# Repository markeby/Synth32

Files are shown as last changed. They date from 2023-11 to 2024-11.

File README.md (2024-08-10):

# Synth32

This project was begun as a darivative of much simpler projects.

The goal is a psudo polyphonic analog and/or multi-timbral synthesizer that is digitally controlled.  

Utilizing components from the following manufacturers:

- Espressif 
  - ESP32 processors
- Sound Semiconductor, FatKeys™
  - VCO, VCF, VCA
- Adafruit
  - D/A Converter modules, I/O Expanders
- HiLetgo
  - 2.0 ADK Mini USB Host Shield
- Waveshare
  - Display module

The core of the system is an ESP-WROOM-32 ESP32 ESP-32S development board with a  USB development shield to interface a midi keyboard.
Any midi controller will work.  I am using an inexpensive Smason Graphite 49 on the serial MIDI and a Novation LaunchControl XL on the USB MIDI.
I intend to add bluetooth MIDI input as well.

The design is for 6 simultanous notes whether they be all of the same effect or split the keyboard to have dual effects but still be able to play cords.

This project has been on going for over a year now and will likely be a few more years of effort.

I have full schematics included as well as some of the experimental work I have done.  This is an unconventio02222nal modular design so as to maintain complete digital control. 

The tools used are:

- KiCad
- Visual SlickEdit IDE - I have used this for over 20 years and have tried others but found them either missing features or a colossal amount of plugins to figure out.
- Arduino-cli 
- Gnu make for Windows (could be used in Linux as well)
- Arduino IDE - I only am using the loader tool for OTA updates of the primary processor
- SimplySerial - The best serial terminal software I have seen for this application debugging.  
  Thanks Edward Wright (fasteddy516).

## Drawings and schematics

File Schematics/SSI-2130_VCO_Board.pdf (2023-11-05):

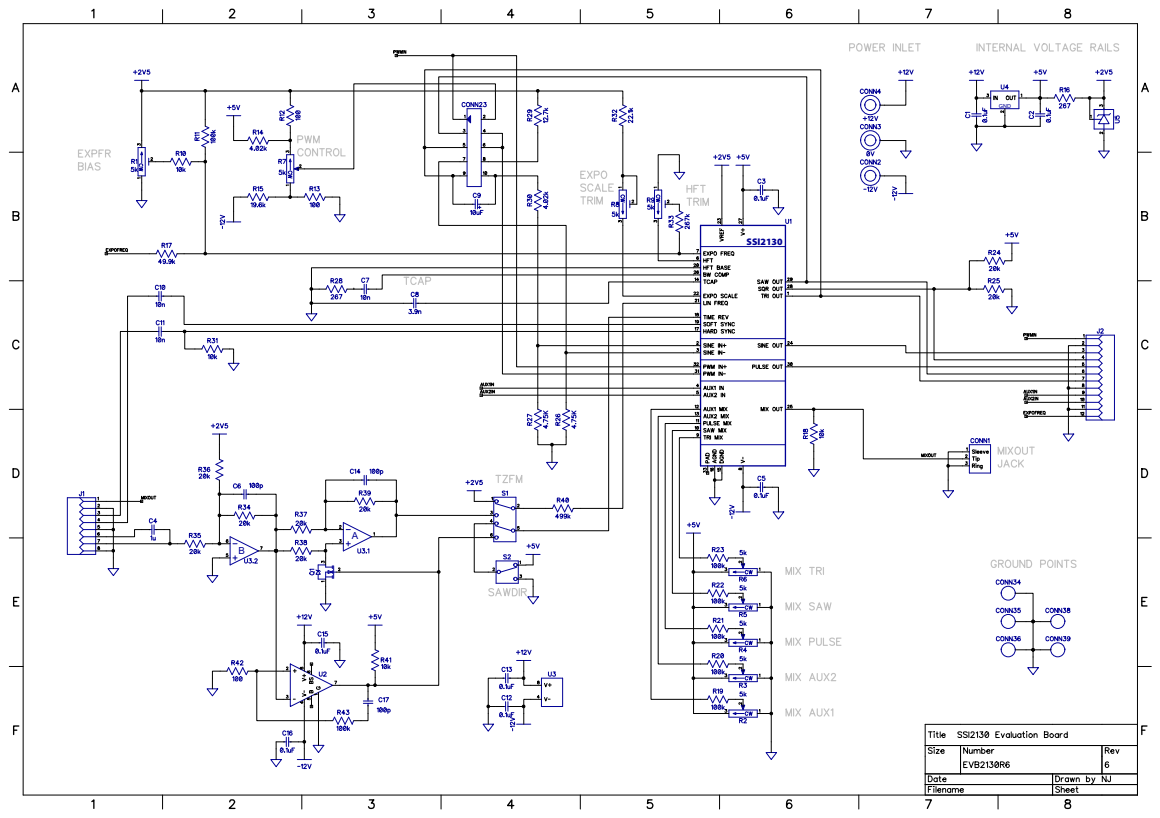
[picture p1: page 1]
SSI2130; GND

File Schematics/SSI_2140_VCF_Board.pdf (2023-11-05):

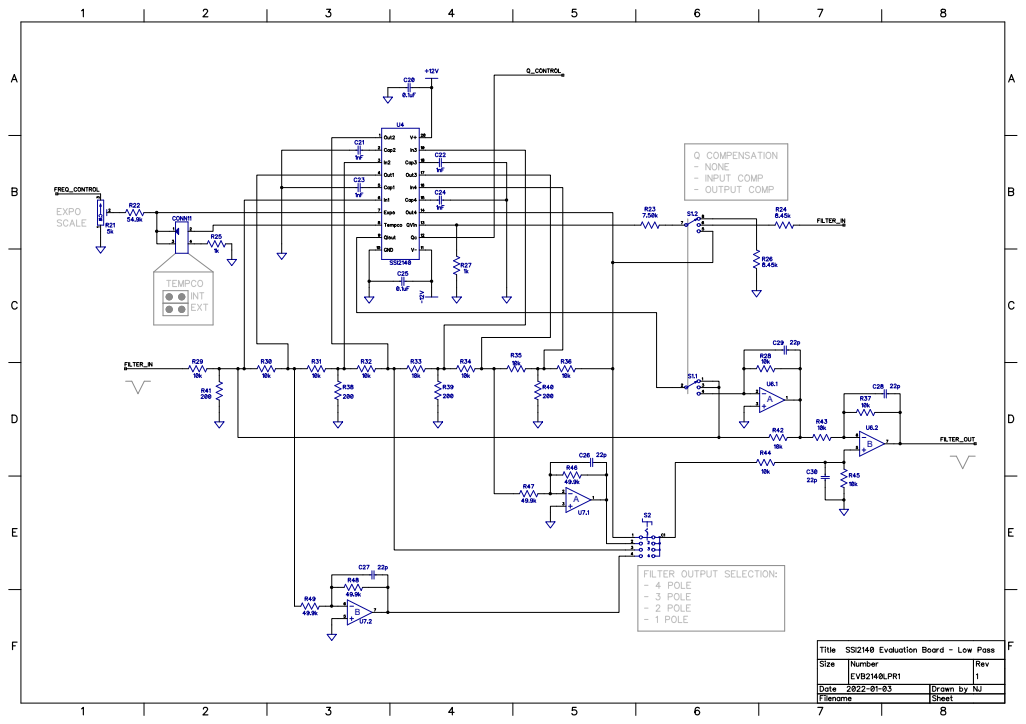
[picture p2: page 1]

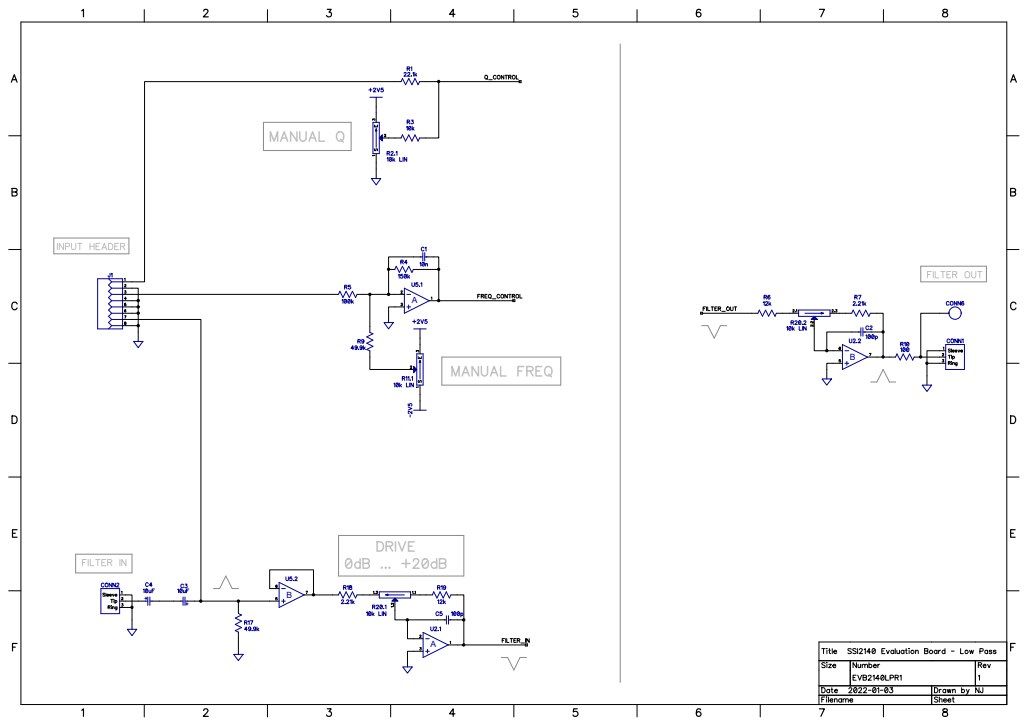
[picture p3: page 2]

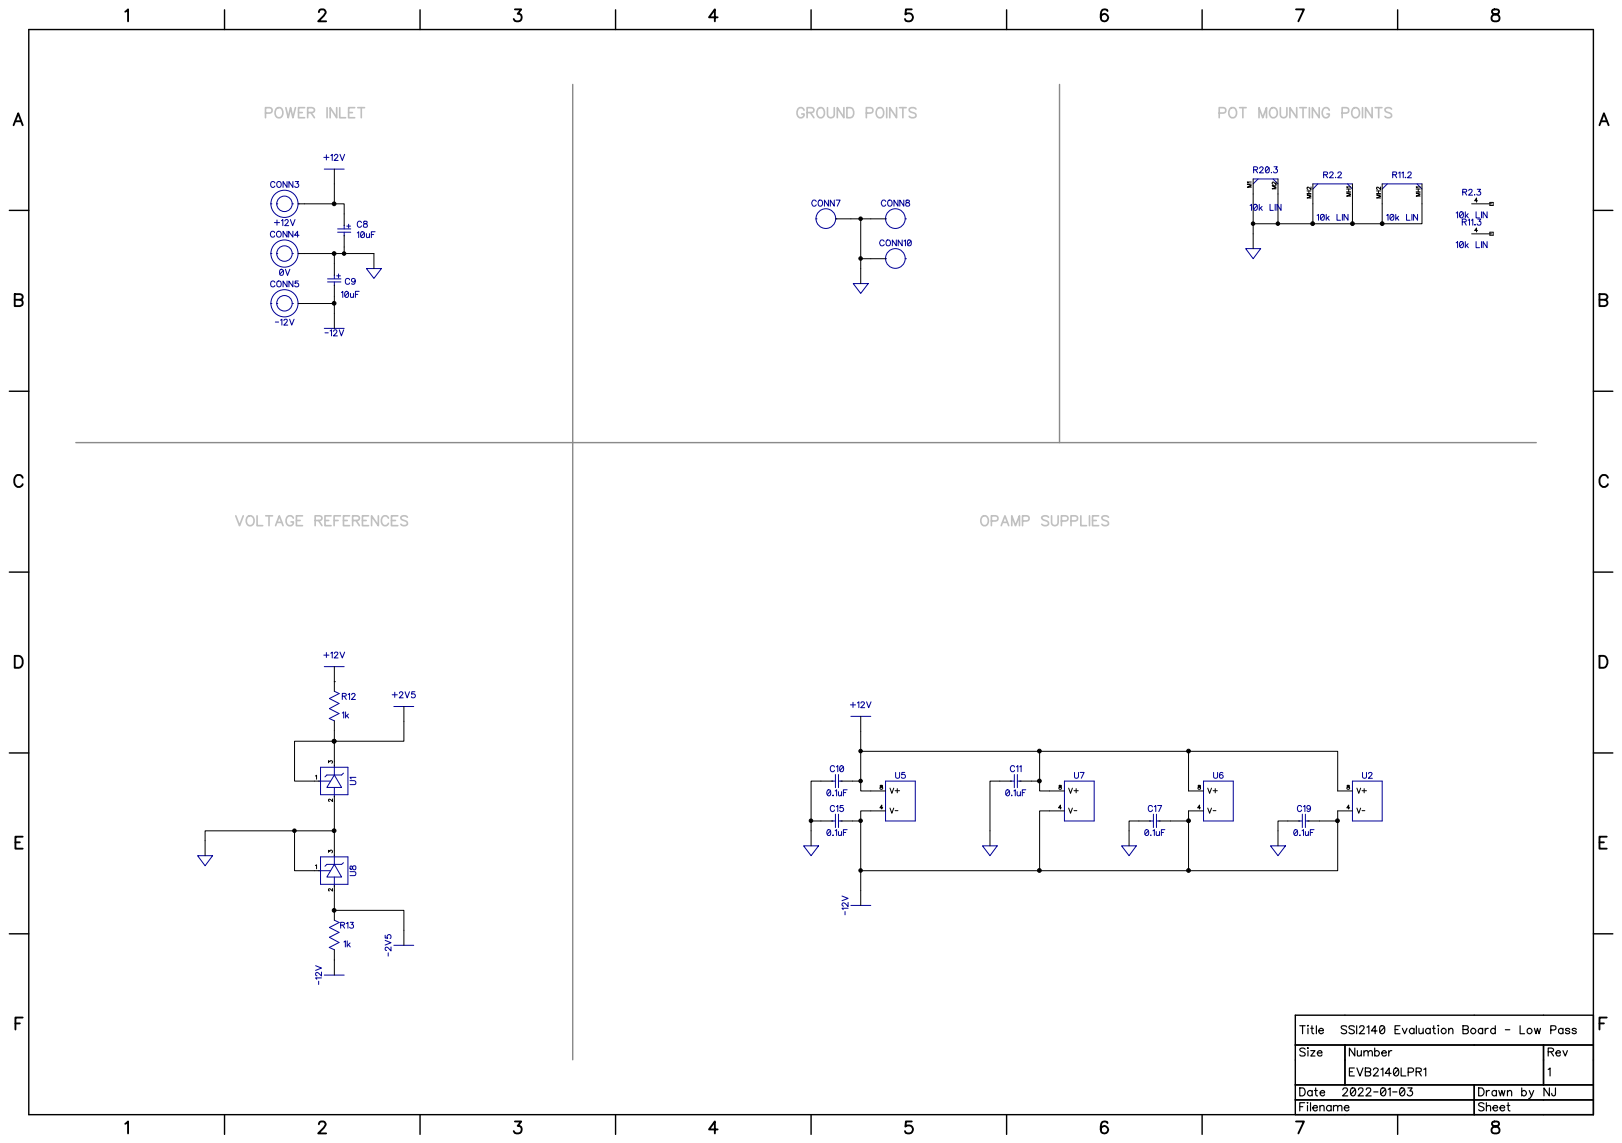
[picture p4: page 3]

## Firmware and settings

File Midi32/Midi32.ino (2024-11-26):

//
// pinout of ESP32 DevKit found here:
// https://circuits4you.com/2018/12/31/esp32-devkit-esp32-wroom-gpio-pinout/
//
#include <Arduino.h>

#include "config.h"
#include "Settings.h"
#include "SerialMonitor.h"
#include "I2Cmessages.h"
#include "FrontEnd.h"
#include "Diagnostics.h"
#include "UpdateOTA.h"

// SET_LOOP_TASK_STACK_SIZE(16 * 1024);  // 16KB

//#######################################################################
I2C_LOCATION_T  BusI2C[] =
//    Cluster   Slice   Channel   DtoA  AtoD    Dig     Name
    { { 0,        0,     0x60,     4,    0,      0,  "D/A #00, 01, 02, 03" },
      { 0,        1,     0x64,     4,    0,      0,  "D/A #04, 05, 06, 07" },
      { 0,        2,     0x60,     4,    0,      0,  "D/A #08, 09, 10, 11" },
      { 0,        3,     0x60,     4,    0,      0,  "D/A #12, 13, 14, 15" },
      { 0,        4,     0x60,     4,    0,      0,  "D/A #16, 17, 18, 19" },
      { 0,        5,     0x60,     4,    0,      0,  "D/A #20, 21, 22, 23" },
      { 0,        6,     0x60,     4,    0,      0,  "D/A #24, 25, 26, 27" },
      { 0,        7,     0x60,     4,    0,      0,  "D/A #28, 29, 30, 31" },
      { 1,        0,     0x60,     4,    0,      0,  "D/A #32, 33, 35, 35" },
      { 1,        1,     0x60,     4,    0,      0,  "D/A #36, 37, 38, 39" },
      { 1,        2,     0x60,     4,    0,      0,  "D/A #40, 41, 42, 43" },
      { 1,        3,     0x60,     4,    0,      0,  "D/A #44, 45, 46, 47" },
      { 1,        4,     0x60,     4,    0,      0,  "D/A #48, 49, 50, 51" },
      { 1,        5,     0x60,     4,    0,      0,  "D/A #52, 53, 54, 55" },
      { 1,        6,     0x60,     4,    0,      0,  "D/A #56, 57, 58, 59" },
      { 1,        7,     0x60,     4,    0,      0,  "D/A #60, 61, 62, 63" },
      { 2,        0,     0x60,     4,    0,      0,  "D/A #64, 65, 66, 67" },
      { 2,        1,     0x60,     4,    0,      0,  "D/A #68, 69, 70, 71" },
      { 2,        2,     0x60,     4,    0,      0,  "D/A #72, 73, 74, 75" },
      { 2,        3,     0x60,     4,    0,      0,  "D/A #76, 77, 78, 79" },
      { 2,        4,     0x60,     4,    0,      0,  "D/A #80, 81, 82, 83" },
      { 2,        5,     0x60,     4,    0,      0,  "D/A #84, 85, 86, 87" },
      { 2,        6,     0x20,     0,    0,     16,  "Dig #88  - 103     " },   // Multiplexer
      { 2,        6,     0x21,     0,    0,     16,  "Dig #104 - 119     " },   // Noise output
      { 2,        7,     0x20,     0,    0,     16,  "Dig #120 - 135     " },   // Digital 48
      { 2,        7,     0x21,     0,    0,     16,  "Dig #136 - 151     " },   // Digital 48
      { 2,        7,     0x22,     0,    0,     16,  "Dig #152 - 167     " },   // Digital 48
      {-1,       -1,       -1,    -1,   -1,     -1,   nullptr }
    };

//#######################################################################
I2C_INTERFACE_C I2cDevices (BusI2C);
SYNTH_FRONT_C   SynthFront (FaderMapArray, KnobMapArray, SwitchMapArray, XlMapArray);

bool       SystemError          = false;
bool       SystemFail           = false;
bool       SynthActive          = false;
float      DeltaTimeMilli       = 0;             // Millisecond interval.
float      DeltaTimeMicro       = 0;             // Microsecond interval
float      DeltaTimeMilliAvg    = 0;
float      LongestTimeMilli     = 0;
uint64_t   RunTime              = 0;
bool       DebugMidi            = false;
bool       DebugI2C             = false;
bool       DebugOsc             = false;
bool       DebugSynth           = false;
bool       DebugDisp            = false;
bool       AnalogDiagEnabled    = false;
int        AnalogDiagDevice     = 0;

//#######################################################################
inline void TimeDelta (void)
    {
    static uint64_t strt = 0;       // Starting time for next frame delta calculation

    RunTime = micros ();
    DeltaTimeMicro = (int)((uint64_t)RunTime - (uint64_t)strt);
    DeltaTimeMilli = MICRO_TO_MILLI (DeltaTimeMicro);
    if ( DeltaTimeMilliAvg == 0 )
        DeltaTimeMilliAvg = DeltaTimeMilli;
    else
        DeltaTimeMilliAvg = (DeltaTimeMilliAvg + DeltaTimeMilli) / 2;
    strt = RunTime;
    if ( DeltaTimeMilli > 210 )     // throw out long serial debug outputs
        return;
    if ( DeltaTimeMilli > LongestTimeMilli )
        LongestTimeMilli = DeltaTimeMilli;
    }

//#######################################################################
inline bool TickTime (void)
    {
    static uint64_t loop_cnt_100hz = 0;
    static uint64_t icount = 0;

    loop_cnt_100hz += DeltaTimeMicro;
    icount++;

    if ( loop_cnt_100hz >= MILLI_TO_MICRO (10)  )
        {
        loop_cnt_100hz = 0;
        icount = 0;
        return (true);
        }
    return (false);
    }

//#######################################################################
inline void TickState (void)
    {
    static uint32_t counter0 = 1;

    if ( --counter0 == 0 )
        {
        digitalWrite (HEARTBEAT_PIN, HIGH);     // LED on
        counter0 = 100;
        }
    if ( SystemError || SystemFail )
        {
        if ( counter0 % 4 )
            {
            digitalWrite (BEEP_PIN, LOW);       // Tone off
            digitalWrite (HEARTBEAT_PIN, LOW);  // LED off
            }
        else
            {
            digitalWrite (BEEP_PIN, HIGH);      // Tone on
            digitalWrite (HEARTBEAT_PIN, HIGH); // LED on
            }
        }
    if ( counter0 == 98 )
        digitalWrite (HEARTBEAT_PIN, LOW);      // LED off
    }


//#######################################################################
//#######################################################################
void setup (void)
    {
    bool fault = false;
    Serial.begin (115200);

    printf ("\t>>> Start Settings config...\n");
    Settings.Begin ();    // System settings

    pinMode (HEARTBEAT_PIN, OUTPUT);
    pinMode (BEEP_PIN,      OUTPUT);
    digitalWrite (BEEP_PIN, LOW);           // Tone off
    digitalWrite (HEARTBEAT_PIN, LOW);      // LED off

    printf ("\t>>> Startup OTA...\n");
    UpdateOTA.Setup (Settings.GetSSID (), Settings.GetPasswd ());

    printf ("\t>>> Starting I2C & devices...\n");
    int errcnt = I2cDevices.Begin ();
    if ( errcnt > 0 )
        {
//        if ( errcnt == I2cDevices.NumBoards () )
            SystemFail = true;
//        else
            SystemError = true;
        }
    if ( SystemFail )
        Serial << "*******  Synth interface is not operational *******" << endl << endl << endl;


    printf ("\t>>> System startup complete.\n");
    if ( SystemError )
        {
        printf ("\t>## Not starting synth.\n");
        }
    else
        {
        printf ("\t>>> Starting Synth...\n");
        SynthActive = true;

        // Setup initial state of synth
        SynthFront.Begin (START_OSC_ANALOG, START_MULT_DIGITAL, START_NOISE_DIGITAL);

        printf ("\t>>> Starting display communications.\n");
        DisplayMessage.Begin (DISPLAY_I2C_ADDRESS, MSG_SDA, MSG_SCL);

        delay (1500);   // Give time for the graphics subsystem threads to start and Wifi to connect

        SynthFront.DisplayUpdate (SynthFront.CurrentZone);

        SynthFront.Multiplex ()->SetOn(MULT_N::MULT_SOURCE::OSC, MULT_N::MULT_GROUP::ALL, MULT_N::MULT_OUTPUT::DIRECT);
        printf("\t>>> Synth ready.\n");
        }
    }

//#######################################################################
void loop (void)
    {
    static bool first = true;

    TimeDelta ();
    if ( TickTime () )
        TickState ();

    // Wifi connection manager
    if ( !UpdateOTA.WiFiStatus () )
        UpdateOTA.WaitWiFi ();

    if ( SynthActive )
        {
        SoftLFO.Loop (DeltaTimeMilli);     // Process sine wave for envelope generator modulation
        SynthFront.Loop ();
        if ( DisplayMessage.Loop () )
            SynthFront.DisplayUpdate (SynthFront.CurrentZone);
        }
    else if ( AnalogDiagEnabled )
        AnalogDiagnostics ();

    if ( first )
        {
        if ( RunTime > 5000000 )
            {
            first = false;
            SynthFront.ResetXL ();
            }
        }

    UpdateOTA.Loop ();
    Monitor.Loop ();
    }

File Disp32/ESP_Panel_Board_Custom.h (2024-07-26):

/*
 * SPDX-FileCopyrightText: 2023-2024 Espressif Systems (Shanghai) CO LTD
 *
 * SPDX-License-Identifier: Apache-2.0
 */

#pragma once

// *INDENT-OFF*

/* Set to 1 if using a custom board */
#define ESP_PANEL_USE_CUSTOM_BOARD       (1)         // 0/1

#if ESP_PANEL_USE_CUSTOM_BOARD

////////////////////////////////////////////////////////////////////////////////////////////////////////////////////////
//////////////////////////// Please update the following macros to configure the LCD panel /////////////////////////////
////////////////////////////////////////////////////////////////////////////////////////////////////////////////////////
/* Set to 1 when using an LCD panel */
#define ESP_PANEL_USE_LCD           (1)     // 0/1

#if ESP_PANEL_USE_LCD
/**
 * LCD Controller Name. Choose one of the following:
 *      - GC9A01, GC9B71, GC9503
 *      - ILI9341
 *      - NV3022B
 *      - SH8601
 *      - SPD2010
 *      - ST7262, ST7701, ST7789, ST7796, ST77916, ST77922
 */
#define ESP_PANEL_LCD_NAME          ST7262

/* LCD resolution in pixels */
#define ESP_PANEL_LCD_WIDTH         (800)
#define ESP_PANEL_LCD_HEIGHT        (480)

/* LCD Bus Settings */
/**
 * If set to 1, the bus will skip to initialize the corresponding host. Users need to initialize the host in advance.
 * It is useful if other devices use the same host. Please ensure that the host is initialized only once.
 */
#define ESP_PANEL_LCD_BUS_SKIP_INIT_HOST    (1)     // 0/1
/**
 * LCD Bus Type. Choose one of the following:
 *      - ESP_PANEL_BUS_TYPE_I2C (not ready)
 *      - ESP_PANEL_BUS_TYPE_SPI
 *      - ESP_PANEL_BUS_TYPE_QSPI
 *      - ESP_PANEL_BUS_TYPE_I80 (not ready)
 *      - ESP_PANEL_BUS_TYPE_RGB (only supported for ESP32-S3)
 */
#define ESP_PANEL_LCD_BUS_TYPE      (ESP_PANEL_BUS_TYPE_RGB)
/**
 * LCD Bus Parameters.
 *
 * Please refer to https://docs.espressif.com/projects/esp-idf/en/latest/esp32s3/api-reference/peripherals/lcd.html and
 * https://docs.espressif.com/projects/esp-iot-solution/en/latest/display/lcd/index.html for more details.
 *
 */
#if ESP_PANEL_LCD_BUS_TYPE == ESP_PANEL_BUS_TYPE_SPI

    #define ESP_PANEL_LCD_BUS_HOST_ID           (1)     // Typically set to 1
    #define ESP_PANEL_LCD_SPI_IO_CS             (5)
#if !ESP_PANEL_LCD_BUS_SKIP_INIT_HOST
    #define ESP_PANEL_LCD_SPI_IO_SCK            (7)
    #define ESP_PANEL_LCD_SPI_IO_MOSI           (6)
    #define ESP_PANEL_LCD_SPI_IO_MISO           (-1)    // -1 if not used
#endif
    #define ESP_PANEL_LCD_SPI_IO_DC             (4)
    #define ESP_PANEL_LCD_SPI_MODE              (0)     // 0/1/2/3, typically set to 0
    #define ESP_PANEL_LCD_SPI_CLK_HZ            (40 * 1000 * 1000)
                                                        // Should be an integer divisor of 80M, typically set to 40M
    #define ESP_PANEL_LCD_SPI_TRANS_QUEUE_SZ    (10)    // Typically set to 10
    #define ESP_PANEL_LCD_SPI_CMD_BITS          (8)     // Typically set to 8
    #define ESP_PANEL_LCD_SPI_PARAM_BITS        (8)     // Typically set to 8

#elif ESP_PANEL_LCD_BUS_TYPE == ESP_PANEL_BUS_TYPE_QSPI

    #define ESP_PANEL_LCD_BUS_HOST_ID           (1)     // Typically set to 1
    #define ESP_PANEL_LCD_SPI_IO_CS             (5)
#if !ESP_PANEL_LCD_BUS_SKIP_INIT_HOST
    #define ESP_PANEL_LCD_SPI_IO_SCK            (9)
    #define ESP_PANEL_LCD_SPI_IO_DATA0          (10)
    #define ESP_PANEL_LCD_SPI_IO_DATA1          (11)
    #define ESP_PANEL_LCD_SPI_IO_DATA2          (12)
    #define ESP_PANEL_LCD_SPI_IO_DATA3          (13)
#endif
    #define ESP_PANEL_LCD_SPI_MODE              (0)     // 0/1/2/3, typically set to 0
    #define ESP_PANEL_LCD_SPI_CLK_HZ            (40 * 1000 * 1000)
                                                        // Should be an integer divisor of 80M, typically set to 40M
    #define ESP_PANEL_LCD_SPI_TRANS_QUEUE_SZ    (10)    // Typically set to 10
    #define ESP_PANEL_LCD_SPI_CMD_BITS          (32)    // Typically set to 32
    #define ESP_PANEL_LCD_SPI_PARAM_BITS        (8)     // Typically set to 8
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

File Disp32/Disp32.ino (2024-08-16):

//#######################################################################
// Module:     Disp32.cpp
// Descrption: Display for Synt32
// Creator:    markeby
// Date:       7/11/2024
//#######################################################################
#include <Arduino.h>

#include "config.h"
#include "Settings.h"
#include "SerialMonitor.h"
#include "Graphics.h"
#include "../Common/DispMessages.h"
#include "ClientI2C.h"

//#######################################################################

float      DeltaTime           = 0;
int        DeltaMicro          = 0;             // micro second interval.
float      AverageDeltaTime    = 0;
uint64_t   RunTime             = 0;

bool       DebugInterface      = false;
bool       DebugGraphics       = false;

//#######################################################################
inline void TimeDelta (void)
    {
    static uint64_t strt = 0;
    static uint64_t loop_cnt_10hz = 0;
    static uint64_t icount = 0;

    uint64_t current =  micros ();
    DeltaMicro = (int)(current - strt);
    strt = current;
    DeltaTime = MICRO_TO_MILLI (DeltaMicro);

    RunTime       += DeltaMicro;
    loop_cnt_10hz += DeltaMicro;
    icount++;

    if ( loop_cnt_10hz >= MILLI_TO_MICRO (100)  )
        {
        AverageDeltaTime = MICRO_TO_MILLI (loop_cnt_10hz / icount);
        loop_cnt_10hz = 0;
        icount = 0;
        }
    }

//#######################################################################
//#######################################################################
void setup (void)
    {
    bool fault = false;
    Serial.begin (115200);

    printf ("\t>>> Start Settings config...\n");
    Settings.Begin ();

    printf ("\t>>> Startup Graphics...\n");
    Graphics.Begin ();

    printf ("\t>>> Startup I2C inputs...\n");
    Client.Begin (DISPLAY_I2C_ADDRESS);
    delay (1500);   // Give time for the graphics subsystem threads to start

    printf ("\t>>> System startup complete.\n\n");

    pinMode (MIDI_TRIGGER_PORT, OUTPUT);
    }

//#######################################################################
//#######################################################################
void loop (void)
    {
    static bool first = true;

    TimeDelta ();

    Client.Process ();

    Monitor.Loop ();
    if ( first )
        {
        Client.TriggerInitialMsgs ();
        first = false;
        }
    }

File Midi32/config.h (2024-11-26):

// config.h
//
// Project settings here (defines, numbers, etc.)

#pragma once

#include <Streaming.h>

#include "../Common/SynthCommon.h"
#include "I2Cdevices.h"

//#####################################
// Usefull constants
//#####################################
#define MICRO_TO_MILLI(x) ((x) * 0.001)
#define MILLI_TO_MICRO(x) ((x) * 1000)

//#####################################
// In case I get confused with Python
//#####################################
#define False false
#define True  true

//#####################################
//   debug controls
//#####################################
extern bool DebugMidi;
extern bool DebugI2C;
extern bool DebugOsc;
extern bool DebugSynth;
extern bool DebugDisp;
extern bool AnalogDiagEnabled;

//#################################################
//   Alarms and alerts
//#################################################
#define HEARTBEAT_PIN       2
#define BEEP_PIN            15

//#################################################
//    Serial 1 MIDI echo out port
//#################################################
#define RXD1        35
#define TXD1        32

//#################################################
//    Serial 2 MIDI echo out port
//#################################################
#define RXD2        16
#define TXD2        17

//#################################################
//    Display message parameters and I2C
//#################################################
#define MSG_ADRS                0x51
#define MSG_SCL                 25
#define MSG_SDA                 26
#define RESET_STROBE_IO         27
#define DISPLAY_SETTLE_TIME     200000

//#################################################
//  Synth I2C interface starting indexes
//#################################################
#define START_OSC_ANALOG        0
#define START_MULT_DIGITAL      88
#define START_NOISE_DIGITAL     104
#define D_A_COUNT               88

//#################################################
//   Global system variables
//#################################################
extern bool     SynthActive;

extern bool     SystemError;
extern bool     SystemFail;
extern float    DeltaTimeMilli;
extern float    DeltaTimeMicro;
extern float    LongestTimeMilli;
extern float    DeltaTimeMilliAvg;
extern uint64_t RunTime;

//#################################################
//    Synth specific constants
//#################################################
#define MIDI_PORT           0        // sometime referred to as cable number
#define FULL_KEYS           128
#define DA_RANGE            4096
#define MAX_DA              (DA_RANGE - 1)
#define NOTES_PER_OCTAVE    12

//#################################################
//    Midi control mapping
//#################################################
typedef struct
    {
    byte        Index;
    const char* Desc;
    void       (*CallBack)(byte chan, byte data);
    }  MIDI_MAP;
typedef struct
    {
    byte        Index;
    byte        Color;
    const char* Desc;
    void       (*CallBack)(byte chan, byte data);
    }  MIDI_XL_MAP;


typedef byte  LED_NOTE_MAP;

//#################################################
//  Synth interfaces
//#################################################
extern MIDI_MAP       FaderMapArray[];
extern MIDI_MAP       KnobMapArray[];
extern MIDI_MAP       SwitchMapArray[];
#define SIZE_CL_MAP   56
#define SIZE_S_LED    24
extern MIDI_XL_MAP    XlMapArray[SIZE_CL_MAP];
extern LED_NOTE_MAP   SendA[];
extern LED_NOTE_MAP   SendB[];
extern LED_NOTE_MAP   PanDevice[];

//#################################################
//  I2C bus interfaces
//#################################################
extern  I2C_INTERFACE_C I2cDevices;

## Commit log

2023-11-05 adding in schematics .
    [Analog-1.kicad_sch, Analog-52channel.kicad_sch, DigitalOptical.kicad_sch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]
2023-11-08 Now with dual ESP32 with Midi32 and Disp32.
    [Analog-1.kicad_sch, DigitalOptical.kicad_sch, Digitial-1.kicad_sch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]
2023-11-11 Disp32 interface working properly.
    [Analog-1.kicad_sch, DigitalOptical.kicad_sch, Digitial-1.kicad_sch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]
2023-11-30 working with Arduino_GFX_library.
2023-12-30 Noise generator and experimental steups.
    [Analog-1.kicad_sch, DigitalOptical.kicad_sch, LFO-1.kicad_sch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]
2024-01-15 adding noise source and variable state filter.
    [Analog-1.kicad_sch, DigitalOptical.kicad_sch, Digitial-1.kicad_sch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]
2024-02-23 Noise boards added.
    [Analog-1.kicad_sch, DigitalOptical.kicad_sch, Digitial-1.kicad_sch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]
2024-03-04 Update with noise filter & VCA as well as envelope generator software shell.
    [DigitalOptical.kicad_sch, LFO-1.kicad_sch, Mixer1.kicad_sch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]
2024-04-01 sync up first noise board.
    [LFO-1.kicad_sch, Mixer1.kicad_sch, Noise.kicad_sch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]
2024-06-07 Partial software with complete hardware on best 3 state filter with 4 outputs.
    [3PoleStateVarVCF.kicad_sch, Analog-1.kicad_sch, DigitalOptical.kicad_sch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]
2024-07-08 partial rework of 3 state filter and display to 7 inches.
    [Multiplexer.kicad_sch]
2024-07-21 - Updated current libraries - New 7 inc display with ESP32S3 and second USB upload port - Start of I2C feeder interface slave on display.
    [Analog-1.kicad_sch, DigitalOptical.kicad_sch, Digitial-1.kicad_sch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]
2024-07-26 working interface for 7 inch display with occasional faults.
    [Digitial-1.kicad_sch, LFO-1.kicad_sch, Noise.kicad_sch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]
2024-07-28 Reset handshake completed.
    [Digitial-1.kicad_sch]
2024-08-02 Completed oscillator page on disp.
    [DispMessages.h, I2Cmessages.cpp, Midi32.ino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]
2024-08-02 Fixed envelope to start decay at the level current instead of maximum.
2024-08-03 Added functional tremelo with software sine wave output.
    [Digitial-1.kicad_sch]
2024-08-10 Added LaunchControlXL
    [Power-Distrib.kicad_sch]
2024-08-16 More major rework for modulators. More display needed.
    [ClientI2C.cpp, Disp32.ino, DispMessages.h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]
2024-10-31 updated schematics.
    [Analog-1.kicad_sch, Mixer1.kicad_sch, Multiplexer.kicad_sch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]
2024-11-01 updated tuning display cnd cleanup of old noise system to add noise to primary VCA channel in Osc devices. Also added 16 control bits for mixer #1.
    [ClientI2C.cpp, DispMessages.h, FrontEnd.cpp]
2024-11-07 Added first level audio mux and fixed tuning control.
    [Multiplexer.kicad_sch]
2024-11-26 Prelude to split configurations.
    [DigitalOptical.kicad_sch, Multiplexer.kicad_sch, Noise.kicad_sch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]
